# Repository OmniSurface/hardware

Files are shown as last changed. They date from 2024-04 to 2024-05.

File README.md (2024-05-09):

This repo stores hardware design files and datasheets of components we used.

## Files
- `datasheet`: this folder stores datasheets of the ICs/sensors we used.
- `img`: pictures of circuit diagrams
- `kicad components`: stores schematic files and footprints of components
- `tlv2771 breakout`: an easy breakout board for the breadboard testing of the TLV2771 Operational Amplifier chip.
- `piezo_v1`: version 1 of the integrated circuit, including a piezo sensor, preamplification of the sensor reading, and a high sampling rate ADC circuit, which communicates with the MCU (ESP32S3) using the SPI interface.
- `mini_v1`: deleted ADC subcircuit and uses a dual channel amplifier (TLV2722) to amplify readings from both the piezo and bone conducting mic sensor. Uses CR2477 coin cell battery to power the ESP32S3 XIAO.
- `mini_lipo_v1`: same as the `mini_v1`, other than it uses a 30.0mm x 25.5mm x 7.1mm 500mAh lipo battery to power the ESP32S3 XIAO.
- `backup_microphone`: this file includes the testing for the backup plan, which is using microphone as the second sensor if piezo or bone conduction cannot work as expected.

## Circuit Diagrams
### Preamplifier 
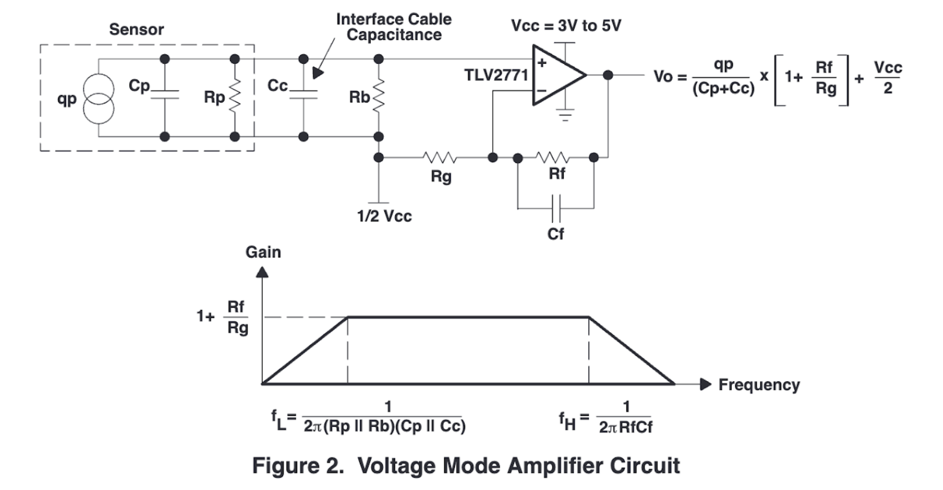
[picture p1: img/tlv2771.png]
tlv2771

- `Vcc` uses 3.3v from the ESP32S3.
- `Rb` = 10MOhm
- `Rg` = 1kOhm
- `Rf` = 56kOhm
- `Cf` is not used, since we want to keep the high-frequency signals.
- `1/2 Vcc` is created using a voltage divider (2 x 10kOhm resistor).

### ADC 
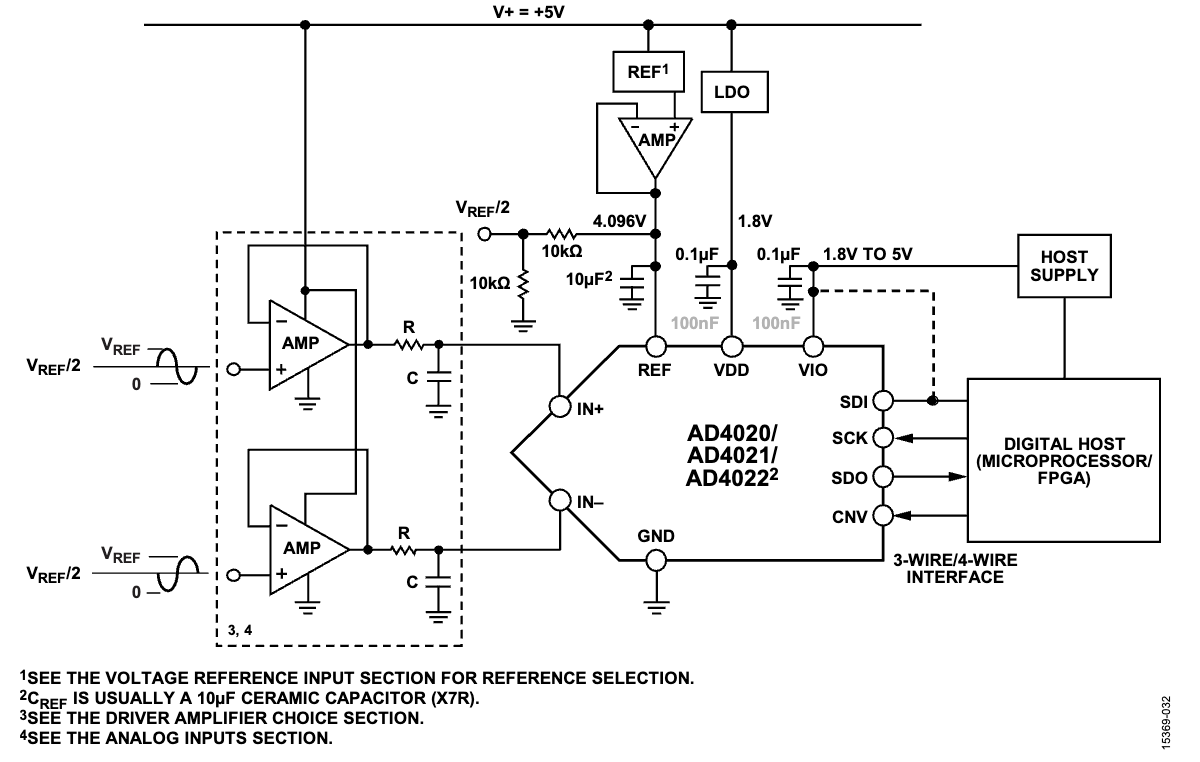
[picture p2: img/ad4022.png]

With some modifications:
- `IN+` of the ADC is connected to the `Vo` of the preamplifier.
- `IN-` of the ADC is connected to `1/2 Vcc`.
- `V+` line and the `VIO` are connected to the 3.3v from the ESP32S3.
- `VREF` = 3v. This means the ADC can convert voltage from -3v to 3v. In our configuration, however, we will only generate signals from -1/2 Vcc to 1/2 Vcc, which is around -1.65v to 1.65v. This will waste 1-bit resolution of the ADC as we only use half of the voltage range. Hope it could still be accurate enough, or we can develop a differential input for the ADC (rather than directly pulling 1/2 Vcc to the `IN-` of the ADC).

## Main Considerations
### Bandwidth
In our preliminary testing using o-scope, a gain of around 50x can produce a desirable signal for all kinds of surface interactions. The TLV2771 amplifier we used has a Gain Bandwidth (GBW) of 5.1 MHz. The formula to calculate the bandwidth of the op-amp when operating at a specific gain is given by:
\[ \text{Bandwidth} = \frac{\text{GBW}}{\text{Gain}} \]
Where,
    - Bandwidth is the frequency at which the gain of the op-amp falls to 1 (unity gain) when operating at a specific gain setting.
    - GBW (Gain-Bandwidth Product) is a characteristic of the op-amp and is usually specified in the datasheet. It's the product of the bandwidth and the gain at which the bandwidth is measured.
    - Gain is the amplification factor at which the op-amp is operating.

In our case, the gain is 50, then the bandwidth is around 100kHz, which could be sufficient in our case of interacting with surfaces.

If a higher GBW turns out to be necessary, we can use LMP7732, which has a GBW of __22MHz__.

### ADC sampling
The AD4022 chip we used for ADC has a maximum sampling rate of around 500kSPS. 

According to the Nyquist theorem, which states that to avoid aliasing, which is the distortion that occurs when the signal is undersampled, the sampling rate must be at least twice the highest frequency present in the signal. This minimum sampling rate is known as the Nyquist rate.
\[ f_{\text{Nyquist}} = 2 \times f_{\text{max}} \]
Where,
 - $f_{\text{max}}$ is the highest frequency component in the signal.

 Given the bandwidth of the preamplifier is 100kHz, our 500kHz sampling rate could be sufficient.

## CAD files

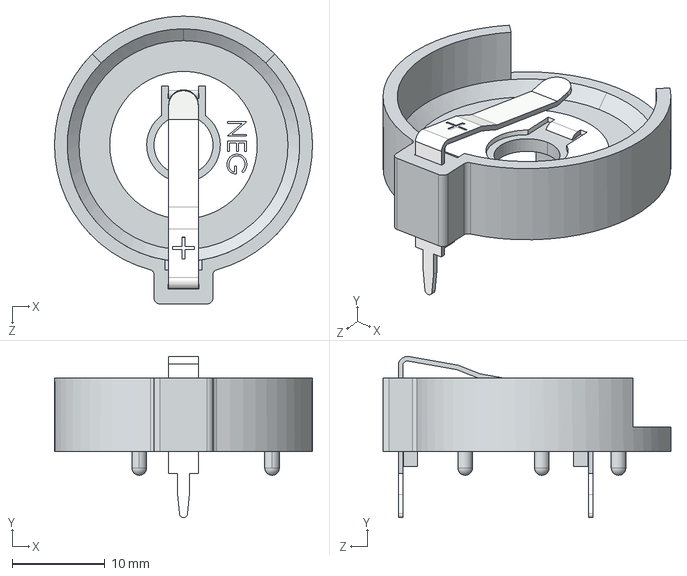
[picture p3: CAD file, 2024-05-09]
kicad components/2477 coin bat holder/1025-7.step
27.8 x 17.3 x 31.0 mm

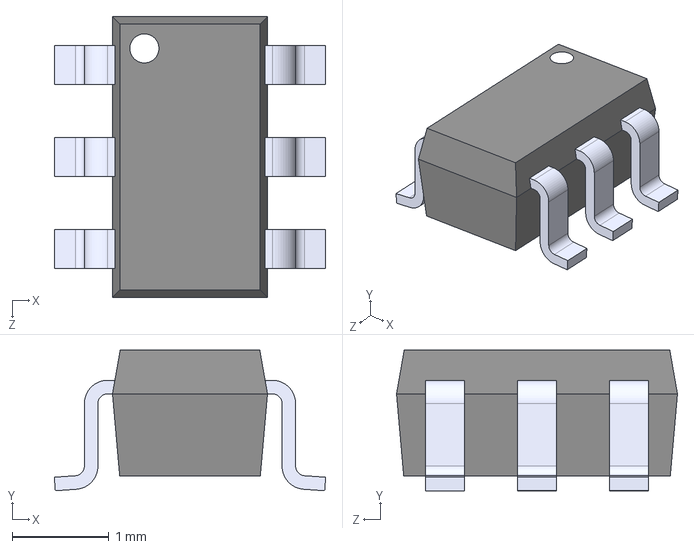
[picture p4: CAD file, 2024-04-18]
kicad components/ADA4807-1ARJZ-R7/ADA4807-1ARJZ-R7.step
2.80 x 1.45 x 2.90 mm

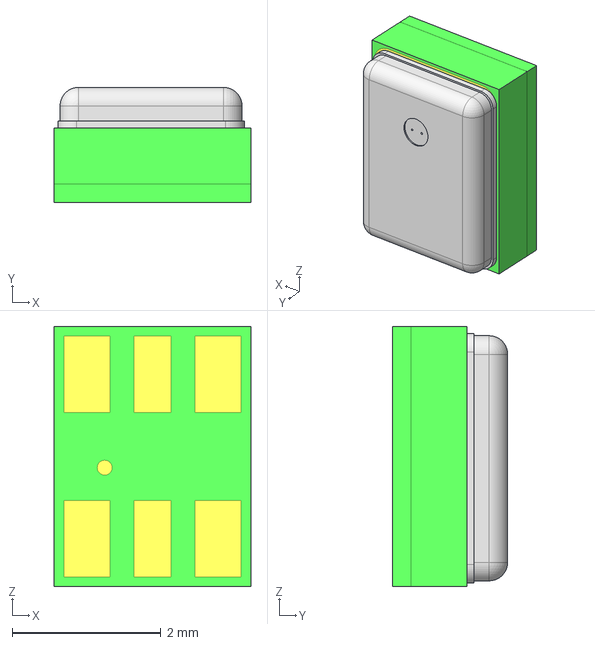
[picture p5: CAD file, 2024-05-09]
kicad components/VMM/VMM-1627L-R.step
2.65 x 1.55 x 3.50 mm

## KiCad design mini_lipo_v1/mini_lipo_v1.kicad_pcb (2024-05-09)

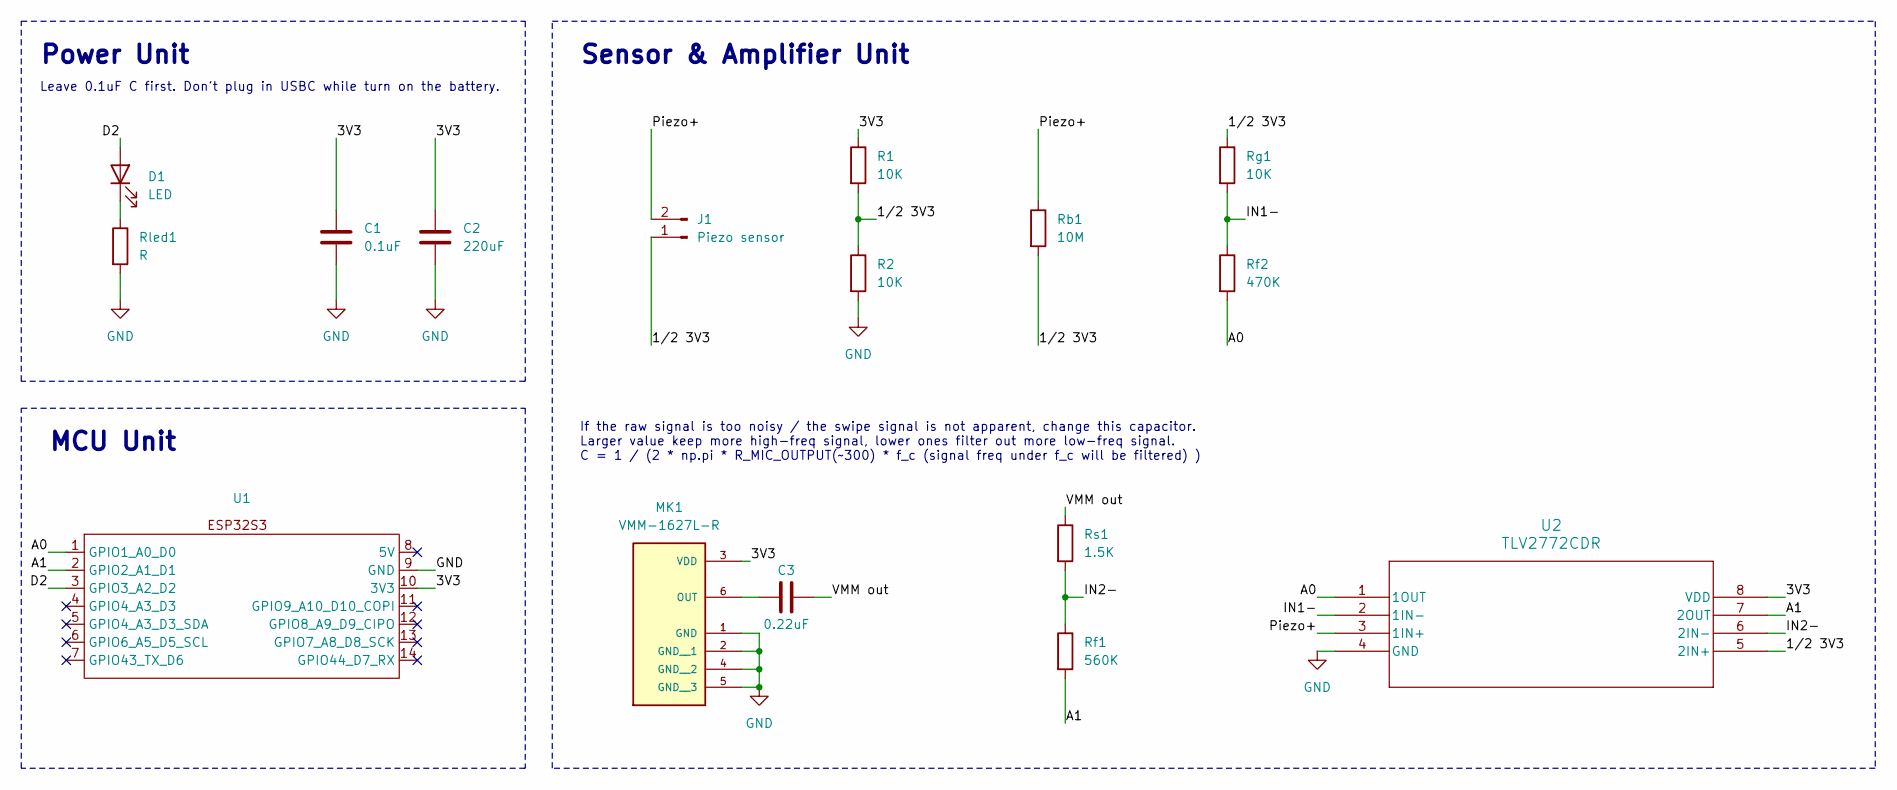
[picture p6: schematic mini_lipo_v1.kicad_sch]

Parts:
C1: 0.1uF; C_0805_2012Metric_Pad1.18x1.45mm_HandSolder
C2: 220uF; 300uF_laydown
C3: 0.22uF; C_0805_2012Metric_Pad1.18x1.45mm_HandSolder
D1: LED; LED_D3.0mm
J1: Piezo sensor; PinHeader_1x02_P2.54mm_Vertical
MK1: VMM-1627L-R; MIC_VMM-1627L-R; PARTREV A
R1, R2: 10K; R_0805_2012Metric_Pad1.20x1.40mm_HandSolder
Rb1: 10M; R_0805_2012Metric_Pad1.20x1.40mm_HandSolder
Rf1: 560K; R_0805_2012Metric_Pad1.20x1.40mm_HandSolder
Rf2: 470K; R_0805_2012Metric_Pad1.20x1.40mm_HandSolder
Rg1: 10K; R_0805_2012Metric_Pad1.20x1.40mm_HandSolder
Rled1: R; C_0805_2012Metric_Pad1.18x1.45mm_HandSolder
Rs1: 1.5K; R_0805_2012Metric_Pad1.20x1.40mm_HandSolder
U1: XIAO_SMD
U2: TLV2772CDR

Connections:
/1/2 3V3: J1.1, R1.2, R2.1, Rb1.2, Rg1.1, U2.5 (2IN+)
/3V3: C1.1, C2.1, MK1.3 (VDD), R1.1, U1.10 (3V3), U2.8 (VDD)
/A0: Rf2.2, U1.1 (GPIO1_A0_D0), U2.1 (1OUT)
/A1: Rf1.2, U1.2 (GPIO2_A1_D1), U2.7 (2OUT)
/D2: D1.2 (A), U1.3 (GPIO3_A2_D2)
/IN1-: Rf2.1, Rg1.2, U2.2 (1IN-)
/IN2-: Rf1.1, Rs1.2, U2.6 (2IN-)
/Piezo+: J1.2, Rb1.1, U2.3 (1IN+)
/VMM out: C3.2, Rs1.1
GND: C1.2, C2.2, MK1.1 (GND), MK1.2 (GND__1), MK1.4 (GND__2), MK1.5 (GND__3), R2.2, Rled1.2, U1.9 (GND), U2.4 (GND)
unnamed: D1.1 (K), Rled1.1
unnamed: C3.1, MK1.6 (OUT)

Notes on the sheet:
Power Unit
Sensor & Amplifier Unit
If the raw signal is too noisy / the swipe signal is not apparent, change this capacitor. Larger value keep more high-freq signal, lower ones filter out more low-freq signal. C = 1 / (2 * np.pi * R_MIC_OUTPUT(~300) * f_c (signal freq under f_c will be filtered) )
MCU Unit
Leave 0.1uF C first. Don't plug in USBC while turn on the battery.

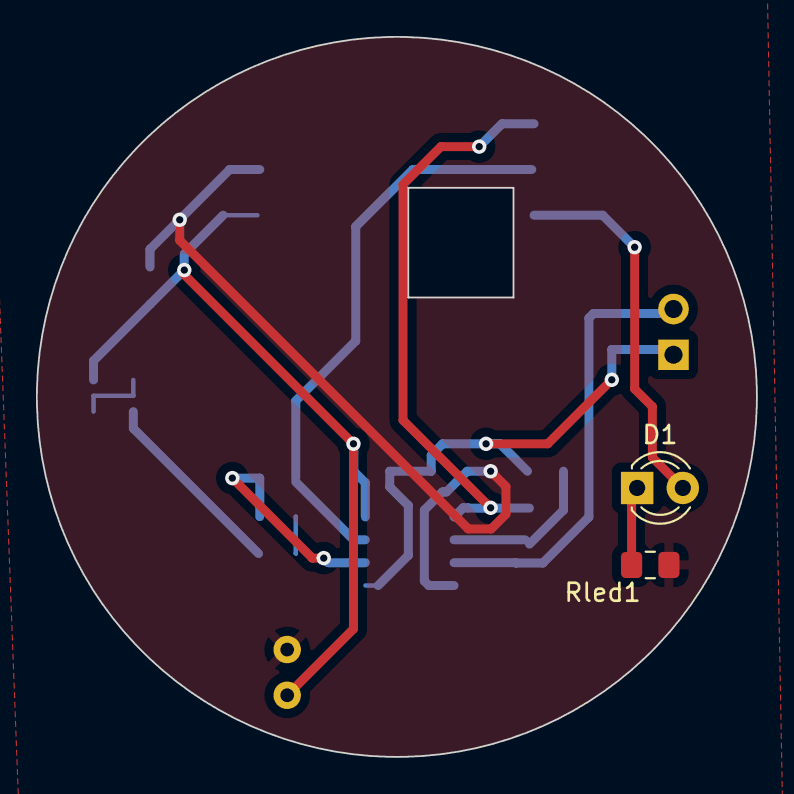
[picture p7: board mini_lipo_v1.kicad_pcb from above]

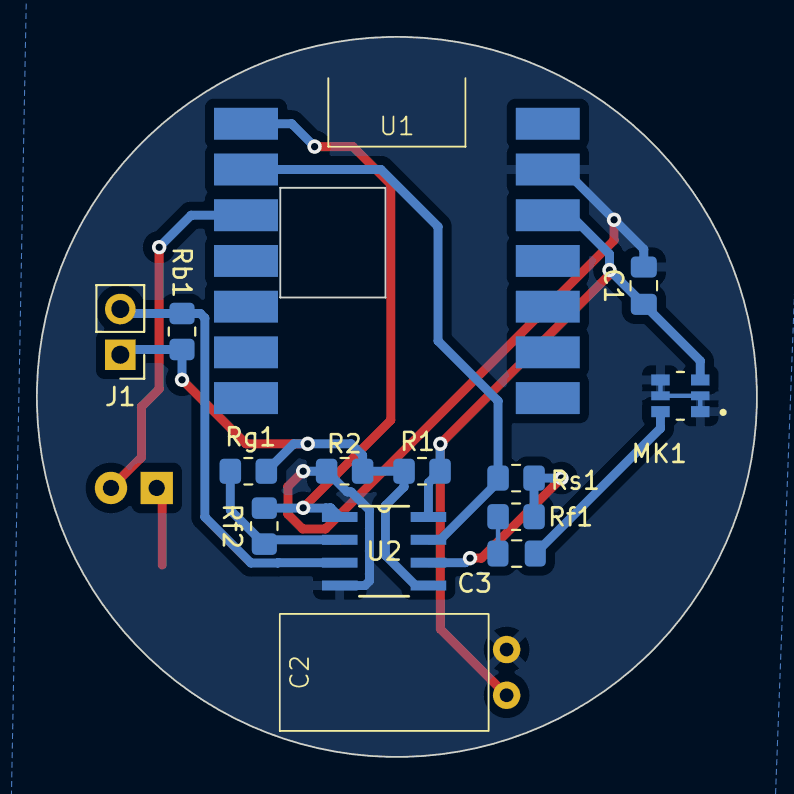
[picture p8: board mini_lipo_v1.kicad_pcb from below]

Board: 2 copper layers, 40.0 x 40.0 mm, 16 parts (14 on the bottom side), 12 nets.

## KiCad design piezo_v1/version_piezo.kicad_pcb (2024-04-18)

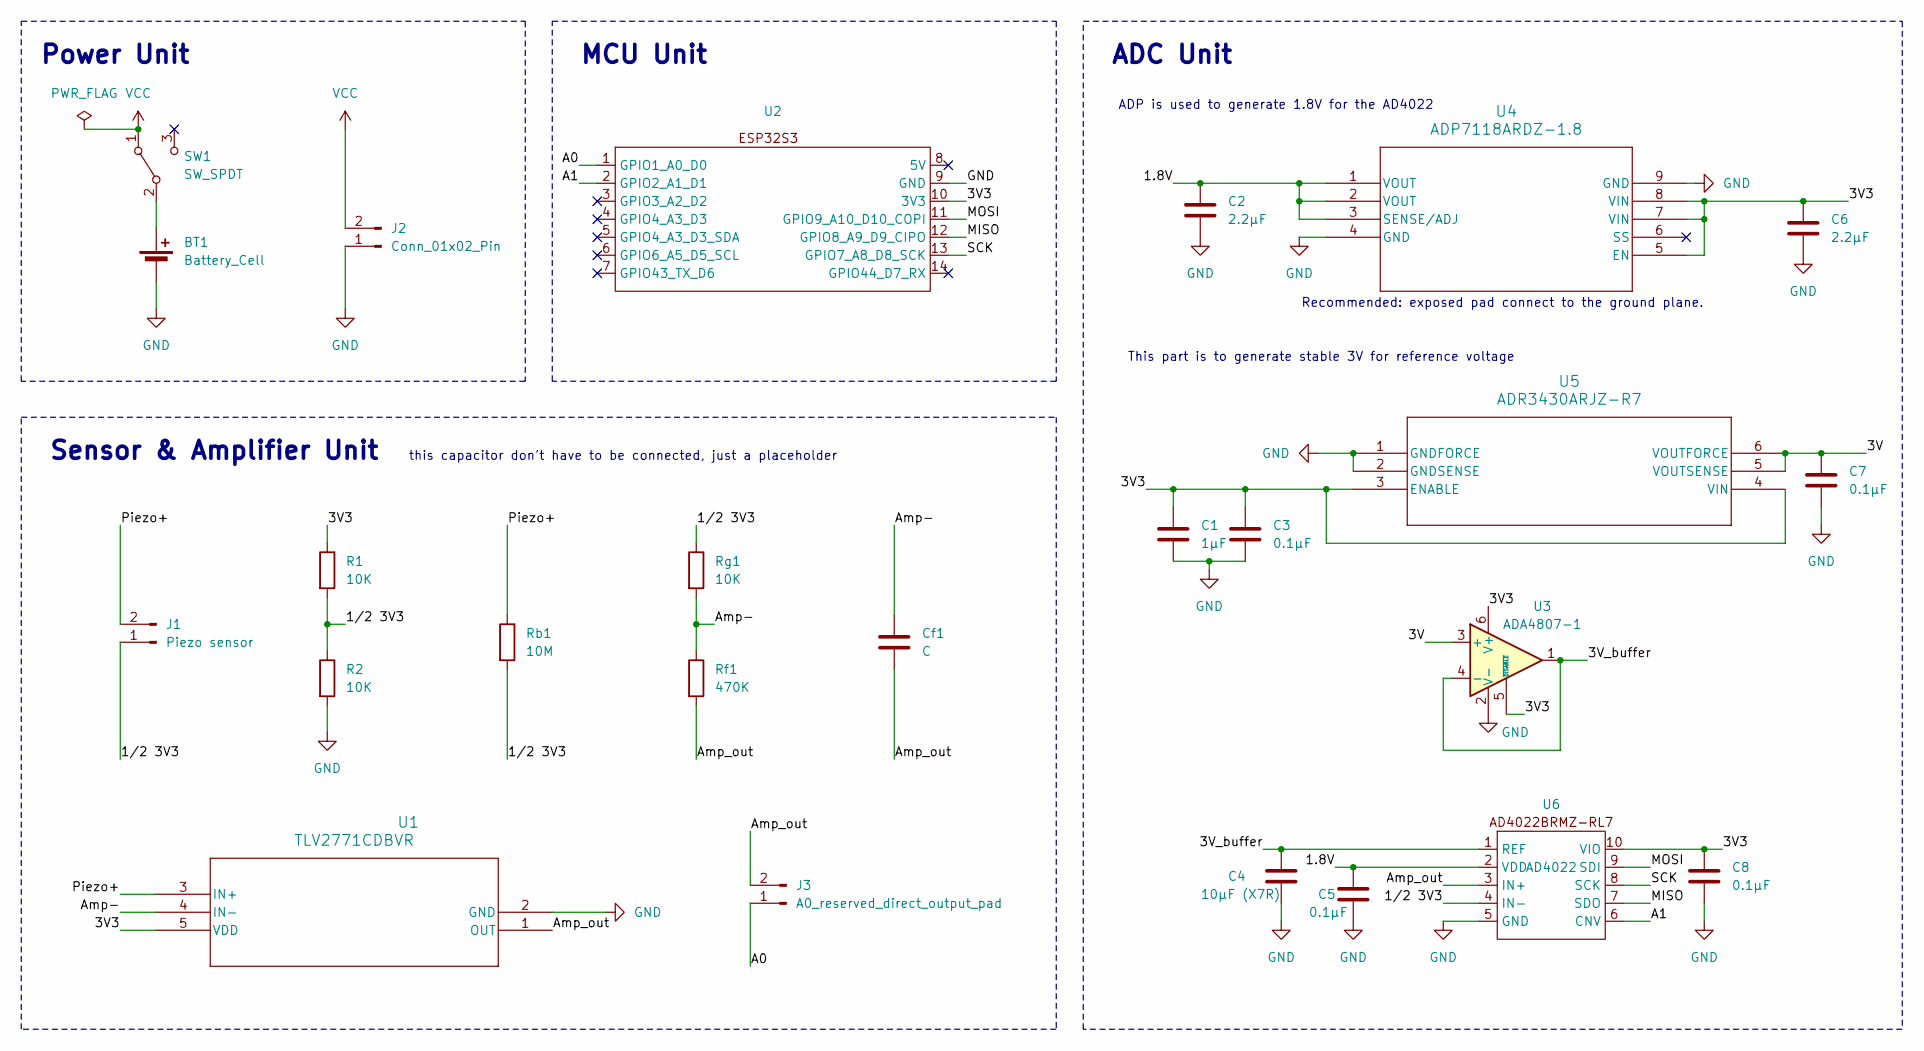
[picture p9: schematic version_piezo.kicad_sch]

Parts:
BT1: Battery_Cell; JST_ZE_SM02B-ZESS-TB_1x02-1MP_P1.50mm_Horizontal
C1: 1μF; C_0805_2012Metric_Pad1.18x1.45mm_HandSolder
C2, C6: 2.2μF; C_0805_2012Metric_Pad1.18x1.45mm_HandSolder
C3, C5, C7, C8: 0.1μF; C_0805_2012Metric_Pad1.18x1.45mm_HandSolder
C4: 10μF (X7R); C_0805_2012Metric_Pad1.18x1.45mm_HandSolder
Cf1: C; C_0805_2012Metric_Pad1.18x1.45mm_HandSolder
J1: Piezo sensor; PinHeader_1x02_P2.54mm_Vertical
J2: Conn_01x02_Pin; LED_D5.0mm
J3: A0_reserved_direct_output_pad; R_0805_2012Metric_Pad1.20x1.40mm_HandSolder
R1, R2: 10K; R_0805_2012Metric_Pad1.20x1.40mm_HandSolder
Rb1: 10M; R_0805_2012Metric_Pad1.20x1.40mm_HandSolder
Rf1: 470K; R_0805_2012Metric_Pad1.20x1.40mm_HandSolder
Rg1: 10K; R_0805_2012Metric_Pad1.20x1.40mm_HandSolder
SW1: SW_SPDT; SWITCH_THT_SPDT_11MA1QS1
U1: TLV2771CDBVR
U2: XIAO_ESP32_SENSE
U3: ADA4807-1; SOT-23-6
U4: ADP7118ARDZ-1.8; SOIC-8-1EP_3.9x4.9mm_P1.27mm_EP2.41x3.81mm
U5: ADR3430ARJZ-R7; SOT-23-6
U6: AD4022; MSOP-10-1EP_3x3mm_P0.5mm_EP1.68x1.88mm

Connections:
/1.8V: C2.1, C5.1, U4.1 (VOUT), U4.2 (VOUT), U4.3 (SENSE/ADJ), U6.2 (VDD)
/1/2 3V3: J1.1, R1.2, R2.1, Rb1.2, Rg1.1, U6.4 (IN-)
/3V: C7.1, U3.3 (+), U5.5 (VOUTSENSE), U5.6 (VOUTFORCE)
/3V3: C1.1, C3.1, C6.1, C8.1, R1.1, U1.5 (VDD), U2.10 (3V3), U3.5 (~DISABLE), U3.6 (V+), U4.5 (EN), U4.7 (VIN), U4.8 (VIN), U5.3 (ENABLE), U5.4 (VIN), U6.10 (VIO)
/3V_buffer: C4.1, U3.1, U3.4 (-), U6.1 (REF)
/A0: J3.1, U2.1 (GPIO1_A0_D0)
/A1: U2.2 (GPIO2_A1_D1), U6.6 (CNV)
/Amp-: Cf1.1, Rf1.1, Rg1.2, U1.4 (IN-)
/Amp_out: Cf1.2, J3.2, Rf1.2, U1.1 (OUT), U6.3 (IN+)
/MISO: U2.12 (GPIO8_A9_D9_CIPO), U6.7 (SDO)
/MOSI: U2.11 (GPIO9_A10_D10_COPI), U6.9 (SDI)
/Piezo+: J1.2, Rb1.1, U1.3 (IN+)
/SCK: U2.13 (GPIO7_A8_D8_SCK), U6.8 (SCK)
GND: BT1.2 (-), C1.2, C2.2, C3.2, C4.2, C5.2, C6.2, C7.2, C8.2, J2.1, R2.2, U1.2 (GND), U2.9 (GND), U3.2 (V-), U4.4 (GND), U4.9 (GND), U5.1 (GNDFORCE), U5.2 (GNDSENSE), U6.5 (GND)
unnamed: BT1.1 (+), SW1.2 (B)
VCC: J2.2, SW1.1 (A)

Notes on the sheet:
Power Unit
Sensor & Amplifier Unit
ADC Unit
this capacitor don't have to be connected, just a placeholder
This part is to generate stable 3V for reference voltage
Recommended: exposed pad connect to the ground plane.
MCU Unit
ADP is used to generate 1.8V for the AD4022

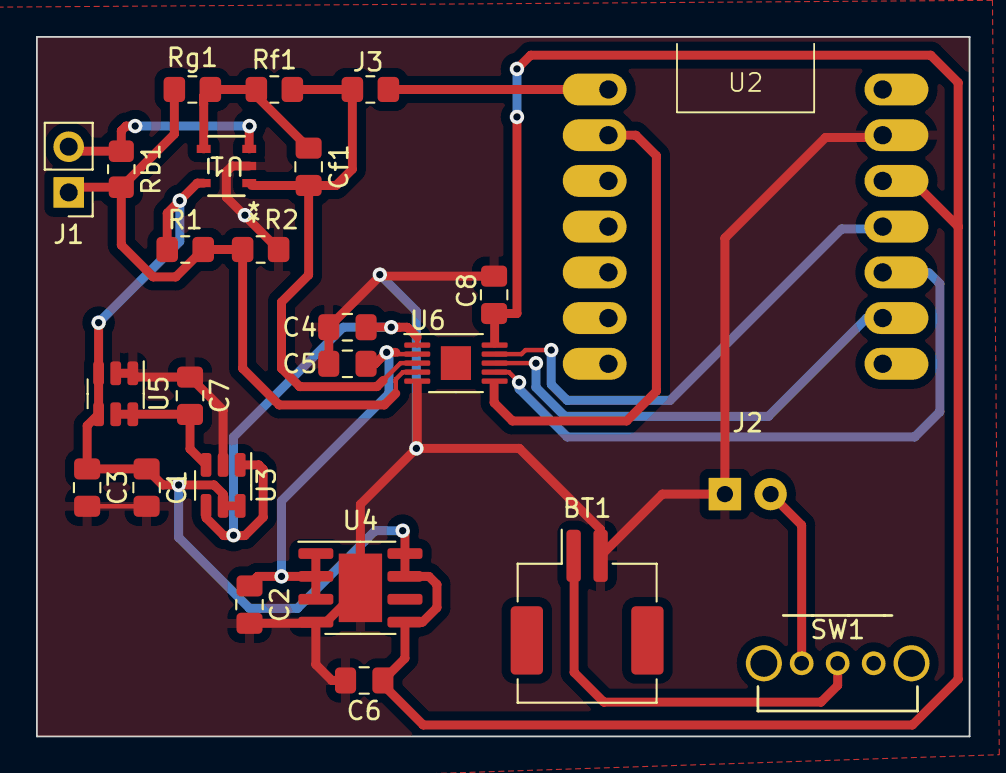
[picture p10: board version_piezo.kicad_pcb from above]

Board: 2 copper layers, 51.8 x 38.9 mm, 25 parts (0 on the bottom side), 16 nets.

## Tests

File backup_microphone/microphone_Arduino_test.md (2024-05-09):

This is the code used in Arduino IED for microphone used to detect gesture vibration.

```bash
# Separately
int ledPin = D2;
const int microphonePin = A0;

void setup() {
  Serial.begin(9600); // Missing semicolon added
  pinMode(ledPin, OUTPUT);
  // Optionally, you could add pinMode(microphonePin, INPUT); here for clarity
}

void loop() {
  int mn = 1024;
  int mx = 0;

  for (int i = 0; i < 100; ++i) {
    int val = analogRead(microphonePin);
    mn = min(mn, val);
    mx = max(mx, val);
  }

  int delta = mx - mn;

  Serial.println(delta); // Corrected function name and case

  if (delta > 200) {
    digitalWrite(ledPin, HIGH); // Corrected case
    delay(1000);
  } else {
    digitalWrite(ledPin, LOW); // Corrected case and added missing semicolon
  } // Added missing closing brace for the if statement block
}
```

```bash
# Combinition
int ledPin = D2;
const int microphonePin = A0;

void setup() {
  Serial.begin(9600); // Missing semicolon added
  pinMode(ledPin, OUTPUT);
  // Optionally, you could add pinMode(microphonePin, INPUT); here for clarity
}

void loop() {
  int mn = 1024;
  int mx = 0;

  for (int i = 0; i < 100; ++i) {
    int val = analogRead(microphonePin);
    mn = min(mn, val);
    mx = max(mx, val);
  }

  int delta = mx - mn;

  Serial.println(delta); // Corrected function name and case

  if (delta > 200) {
    digitalWrite(ledPin, HIGH); // Corrected case
    delay(1000);
  } else {
    digitalWrite(ledPin, LOW); // Corrected case and added missing semicolon
  } // Added missing closing brace for the if statement block
}
```
